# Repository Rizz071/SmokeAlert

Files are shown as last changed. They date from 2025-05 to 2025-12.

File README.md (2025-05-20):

# 🚨 SmokeAlert

**SmokeAlert** — это интеллектуальная беспроводная система пожарной сигнализации, разработанная для обеспечения безопасности в **жилых** и **промышленных** помещениях. Система сочетает в себе **долговечность**, **простоту установки** и **современные технологии связи**.

---

## 🔥 Основные особенности

- 📡 **LoRa 868MHz** — стабильная беспроводная связь с большим радиусом действия, не требующая государственной регистрации.
- 🛠️ **Установка за минуты** — настройка и добавление новых датчиков предельно упрощены.
- 📱 **Интеграция со смартфоном** — мгновенные уведомления и тревоги в приложении (через протокол MQTT, на собственной инфраструктуре).
- 🔋 **Долгий срок службы** — работа каждого датчика от 2 батареек AA до **1 года** без замены.
- ➕ **Гибкая масштабируемость** — к одной базовой станции можно подключить любое нужное количество датчиков.
- 🌐 **Два варианта выхода в интернет**:
  - через **Wi-Fi**
  - через **GSM-модуль**, где нет локальной сети

---

## ⚙️ Применение

- Частные дома и квартиры
- Офисы и административные здания
- Склады, мастерские, производственные помещения
- Объекты без постоянного подключения к WiFi

---

## 🤝 Контакты и вклад

Pull request'ы и предложения приветствуются!  
По вопросам сотрудничества — обращайтесь в [Issues](https://github.com/Rizz071/smokealert/issues) или откройте дискуссию.

---

**SmokeAlert** — безопасность должна быть доступной.

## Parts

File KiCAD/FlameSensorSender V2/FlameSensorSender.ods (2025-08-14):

Reference | Value | Footprint | Datasheet |  | Qty |  | AliExpress | ChipDip | Промэлектроника
BT1 | AA 2pcs | Battery:BatteryHolder_Keystone_2462_2xAA | ~ | Single-cell battery | 1 |  | 76 | 260 | нет
BZ1 | Buzzer SFM-20B | Buzzer_Beeper:Buzzer_12x9.5RM7.6 | ~ | Buzzer, polarized | 1 | https://aliexpress.ru/item/1005006076359267.html?sku_id=12000035619115303 | 56 | нет | нет
C1,C2,C3,C5,C6,C7 | 104,0603 | Capacitor_SMD:C_0603_1608Metric_Pad1.08x0.95mm_HandSolder | ~ | Unpolarized capacitor | 6 | 0.1 мкФ X7R 100В 10% 0603, GRM188R72A104KA35D | 1.4 | 3 | 3
C4 | 105,0603 | Capacitor_SMD:C_0603_1608Metric_Pad1.08x0.95mm_HandSolder | https://search.murata.co.jp/Ceramy/image/img/A01X/G101/ENG/GRM188R60J226MEA0-01.pdf | Unpolarized capacitor | 1 | 1 мкФ X7R 25В 10% 0603, GCM188R71E105KA64D, Конденсатор керамический smd (https://www.chipdip.ru/product/gcm188r71e105ka64d-murata) | 1,4 | 5 | 3
C8 | 16V220u,alum 6.3x7.7 | Capacitor_SMD:CP_Elec_6.3x7.7 | ~ | Polarized capacitor | 1 | ECAP SMD, 220мкФ, 16В, 105°C, 20%, 6.3x7.7мм, JCK1C221M063077, Конденсатор электролитический алюминиевый SMD (https://www.chipdip.ru/product0/9000565741) | 15 | 10 | нет
C9,C10,C13,C12 | 22u,0603 | Capacitor_SMD:C_0603_1608Metric_Pad1.08x0.95mm_HandSolder | https://search.murata.co.jp/Ceramy/image/img/A01X/G101/ENG/GRM188R60J226MEA0-01.pdf | Unpolarized capacitor | 4 | 22мкФ X5R 10В 20% 0603, GRM188R61A226ME15D, Конденсатор керамический smd (https://www.chipdip.ru/product0/9000318419) |  | 5 | 4
C11 | C_Polarized 100uF electrolitic | Capacitor_SMD:CP_Elec_5x5.4 | ~ | Polarized capacitor | 1 | https://aliexpress.ru/item/4000772249207.html?sku_id=10000007734222927 | 8 | 8
D1 | LED | LED_SMD:LED_1206_3216Metric_Pad1.42x1.75mm_HandSolder | ~ | Light emitting diode | 1 | https://aliexpress.ru/item/4000936830233.html?sku_id=10000011314281971 | 1 | 0 | 0
FB1 | FerriteBead | Inductor_SMD:L_0603_1608Metric_Pad1.05x0.95mm_HandSolder | ~ | Ferrite bead | 1 | MPZ1608D101BTA00, Ferrite Beads 100ohms 1A 60mOhms 0603 Ferrite Chip (https://www.chipdip.ru/product0/8006387224) | 3 | 24
J1,J2 | SWD | Connector_PinHeader_2.54mm:PinHeader_2x02_P2.54mm_Vertical | ~ | Generic connector, double row, 02x02, counter clockwise pin numbering scheme (similar to DIP package numbering), script generated (kicad-library-utils/schlib/autogen/connector/) | 2 | https://aliexpress.ru/item/1005006125301583.html?sku_id=12000035866886147 | 10
 | Sharp GP2Y1014AUOF |  |  |  | 1 | S6B-PH-K-S[LF][SN] (https://www.chipdip.ru/product0/8007977843) |  | 7
J3 | Sharp GP2Y1014AUOF | Connector_JST:JST_PH_S6B-PH-K_1x06_P2.00mm_Horizontal | ~ | Generic connector, single row, 01x06, script generated | 1 | PHR-6, Корпус разъема розетка на кабель 2.0 мм 6pin (https://www.chipdip.ru/product/phr-6) | 430 | 18
J4 | JST-PH PHR-2 |  | ~ | Generic connector, single row, 01x02, script generated | 1 | PHR-2, Корпус разъема розетка на кабель 2.0 мм 2pin (https://www.chipdip.ru/product/phr-2-2) |  | 18
J5 | JST-PH B2B-PH-K-S | Connector_JST:JST_PH_S2B-PH-K_1x02_P2.00mm_Horizontal | ~ | Generic connector, single row, 01x02, script generated | 1 | S2B-PH-K-S [LF][SN] (https://www.chipdip.ru/product0/8002744024) |  | 4
J6 | Conn_01x04_Socket | Connector_JST:JST_PH_S4B-PH-K_1x04_P2.00mm_Horizontal | ~ | Generic connector, single row, 01x04, script generated | 1 | S4B-PH-K-S [LF][SN] (https://www.chipdip.ru/product0/8002744025) |  | 7
J7 | Conn_01x04_Pin |  | ~ | Generic connector, single row, 01x04, script generated | 1 | PHR-4, Корпус разъема розетка на кабель 2.0 мм 4pin (https://www.chipdip.ru/product/phr-4) |  | 18
J8 | 6 Pin USB-C Type USB Connector with case |  |  | USB Power-Only 6P Type-C Receptacle connector | 1 | https://aliexpress.ru/item/1005005750734799.html?pdp_trigger_item_id=0_1005006256311650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 | 117
L1,L2 | 0.47u | Footprints:INDC2016X120N | https://search.murata.co.jp/Ceramy/image/img/P02/J(E)TE243A-0006.pdf | Inductor DFE201612E-R47M=P2 | 2 | DFE201612E-R47M=P2 (https://www.chipdip.ru/product0/8008306444) |  | 9
Q1,Q3,Q6 | AO3401A | Package_TO_SOT_SMD:SOT-23-3 | http://www.aosmd.com/pdfs/datasheet/AO3401A.pdf | -4.0A Id, -30V Vds, P-Channel MOSFET, SOT-23 | 3 | AO3401A, Транзистор P-MOSFET 30В 4.2А [SOT-23-3] (https://www.chipdip.ru/product/ao3401a-umw) |  | 4
Q2,Q4,Q5 | AO3400A | Package_TO_SOT_SMD:SOT-23-3 | http://www.aosmd.com/pdfs/datasheet/AO3400A.pdf | 30V Vds, 5.7A Id, N-Channel MOSFET, SOT-23 | 3 | AO3400A, Транзистор N-MOSFET 30В 5.8А 1.4Вт [SOT-23-3.] (https://www.chipdip.ru/product/ao3400a) |  | 10
R1,R2,R7,R11,R12,R16,R17,R19 | 10k,0603 | Resistor_SMD:R_0603_1608Metric_Pad0.98x0.95mm_HandSolder | https://www.vishay.com/docs/20035/dcrcwe3.pdf,~ | Resistor | 8 | 0.1Вт 0603 10 кОм, 1%, AC0603FR-0710KL, Чип резистор (SMD) (https://www.chipdip.ru/product0/9000695897) |  | 6
R3,R8,R18 | 10,0603 | Resistor_SMD:R_0603_1608Metric_Pad0.98x0.95mm_HandSolder | ~ | Resistor | 3 | 0.1Вт 0603 10 Ом, 1%, RC0603FR-0710RL, Чип резистор (SMD) (https://www.chipdip.ru/product/rc0603fr-0710rl-rezistor) |  | 2
R4,R5 | 220,0603 | Resistor_SMD:R_0603_1608Metric_Pad0.98x0.95mm_HandSolder | ~ | Resistor | 2 | 0.1Вт 0603 220 Ом, 1%, RC0603FR-07220RL, Чип резистор (SMD) (https://www.chipdip.ru/product0/9000179829) |  | 2
R6,R10 | 330,0603 | Resistor_SMD:R_0603_1608Metric_Pad0.98x0.95mm_HandSolder | ~ | Resistor | 2 | 0.1Вт 0603 330 Ом, 1%, RC0603FR-07330RL, Чип резистор (SMD) (https://www.chipdip.ru/product0/9000396128) |  | 2
R9 | 150,0603 | Resistor_SMD:R_0603_1608Metric_Pad0.98x0.95mm_HandSolder | ~ | Resistor | 1 | 0603SAF1500T5E, Резистор: thick film, SMD, 0603, 150Ом, 0,1Вт, ±1%, -55-155°C (https://www.chipdip.ru/product0/8007875741) |  | 2
R13,R22 | 100k,0603 | Resistor_SMD:R_0603_1608Metric_Pad0.98x0.95mm_HandSolder | https://www.vishay.com/docs/20035/dcrcwe3.pdf | Resistor | 2 | 0.1Вт 0603 100 кОм, 1%, RC0603FR-07100KL, Чип резистор (SMD) (https://www.chipdip.ru/product0/9000632023) |  | 2
R14 | 511k,0603 | Resistor_SMD:R_0603_1608Metric_Pad0.98x0.95mm_HandSolder | https://www.vishay.com/docs/20035/dcrcwe3.pdf | Resistor | 1 | 0.1Вт 0603 510 кОм, 1%, RC0603FR-07510KL, Чип резистор (SMD) (https://www.chipdip.ru/product/rc0603fr-07510kl-yageo) |  | 2
R15,R24 | 91k,0603 | Resistor_SMD:R_0603_1608Metric_Pad0.98x0.95mm_HandSolder | https://www.vishay.com/docs/20035/dcrcwe3.pdf | Resistor | 2 | 0.1Вт 0603 91 кОм, 1%, RC0603FR-0791KL, Чип резистор (SMD) (https://www.chipdip.ru/product0/9000618649) |  | 2
R20,R21 | 5.1k,0603 | Resistor_SMD:R_0603_1608Metric_Pad0.98x0.95mm_HandSolder | ~ | Resistor | 2 | 0.1Вт 0603 5.1 кОм, 5%, RC0603JR-075K1L, Чип резистор (SMD) (https://www.chipdip.ru/product0/9000103442) |  | 2
R23 | 806k,0603 | Resistor_SMD:R_0603_1608Metric_Pad0.98x0.95mm_HandSolder | https://www.vishay.com/docs/20035/dcrcwe3.pdf | Resistor | 1 | WR06X8063FTL, Thick Film Resistors - SMD 0603 806K 1% Lead Free (https://www.chipdip.ru/product0/8008405525) |  | 30
SW1 | SW_Push | Button_Switch_THT:SW_PUSH_6mm_H4.3mm | ~ | Push button switch, generic, two pins | 1 | 1-1825910-0 (FSM6JH), Кнопка тактовая h=7 мм SPST (https://www.chipdip.ru/product/tyco-1-1825910-0-fsm6jh) |  | 13
SW2 | SW_Push | Button_Switch_SMD:SW_Push_1TS009xxxx-xxxx-xxxx_6x6x5mm | ~ | Push button switch, generic, two pins | 1 | https://aliexpress.ru/item/4000678658427.html?pdp_trigger_item_id=0_1005009311663697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 |  | 5
U1 | STM32F103C6Tx | Package_QFP:LQFP-48_7x7mm_P0.5mm | https://www.st.com/resource/en/datasheet/stm32f103c6.pdf | STMicroelectronics Arm Cortex-M3 MCU, 32KB flash, 10KB RAM, 72 MHz, 2.0-3.6V, 37 GPIO, LQFP48 | 1 | STM32F103C8T6, Микроконтроллер 32-Бит, Cortex-M3, 72МГц, 64КБ Flash, USB, CAN [LQFP-48.] (https://www.chipdip.ru/product/stm32f103c8t6) |  | 140
U2 | Ra-01SCH-P | RF_Module:Ai-Thinker-Ra-01-LoRa | http://wiki.ai-thinker.com/_media/lora/docs/c048ps01a1_ra-02_product_specification_v1.1.pdf | Ai-Thinker Ra-02 410-525 MHz LoRa Module, SPI interface, U.FL antenna connector | 1 | https://aliexpress.ru/item/4001148156263.html?sku_id=12000043451828807 | 299
U3 | TVS0500DRV | Package_SON:WSON-6-1EP_2x2mm_P0.65mm_EP1x1.6mm | http://www.ti.com/lit/ds/symlink/tvs0500.pdf | Flat-Clamp Surge Protection Device. 5Vrwm, WSON-6 | 1 | TVS0500DRVR (https://www.chipdip.ru/product0/8003874408) |  | 110
U4,U6 | TPS63802DLAR | Footprints:VREG_TPS63802DLAR | https://www.ti.com/lit/ds/symlink/tps63802.pdf?ts=1746895174737 |  | 2 | TPS63802DLAR, Buck-boost преобразователь напряжения ADJ VSON-HR-10(3x2) (https://www.chipdip.ru/product/tps63802dlat) |  | 130
U5 | TPS2116DRL | Package_TO_SOT_SMD:SOT-583-8 | https://www.ti.com/lit/ds/symlink/tps2116.pdf | 2 Channnels Power Mux with Manual and Priority Switchover, 1.6-5.5V Input Voltage, 2.5A Output Current, Ron 40 mOhm, SOT-583-8 | 1 | TPS2116DRLR, Выключатель распределения питания SOT-583 (https://www.chipdip.ru/product0/8048099577) |  | 87
 |  |  |  |  | 12 | SPH-002T-P0.5L (https://www.chipdip.ru/product/sph-002t-p0.5l) | 3

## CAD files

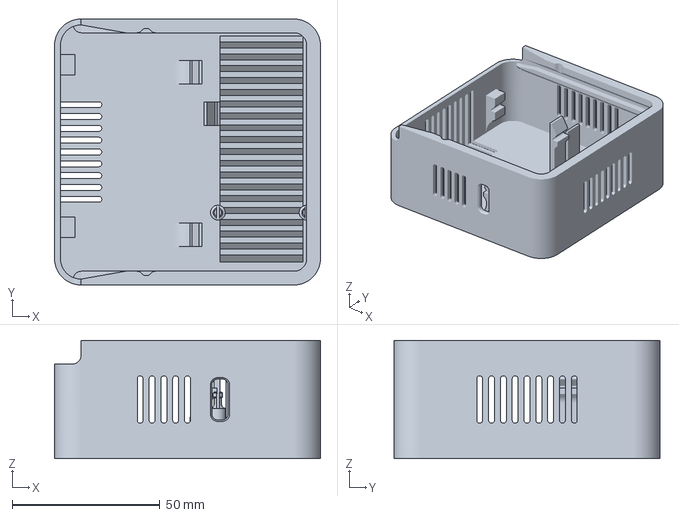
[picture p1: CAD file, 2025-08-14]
Creo/SensorSender/prt0001.3mf
90.0 x 90.0 x 40.0 mm

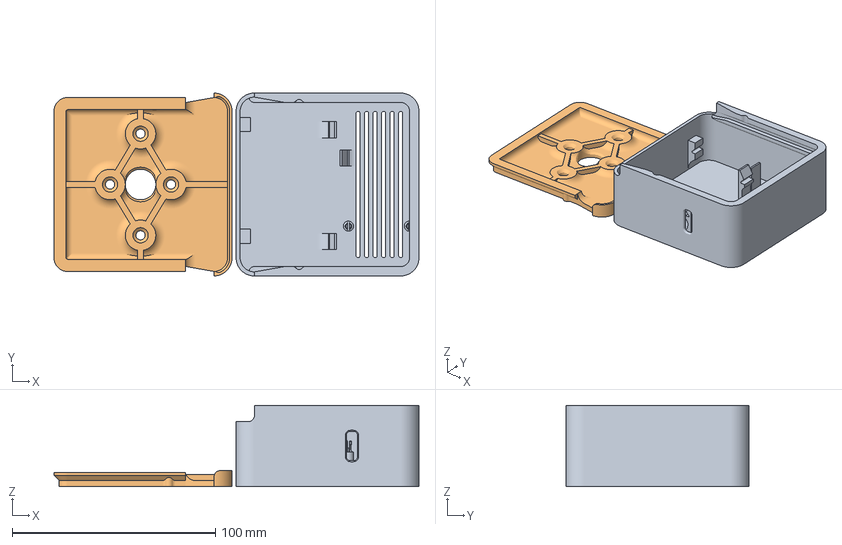
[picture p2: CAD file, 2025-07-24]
Creo/SensorSender_Sharp_sensor/prt0001.3mf
179.6 x 90.0 x 40.0 mm
prt0001.stp
prt0005.stp

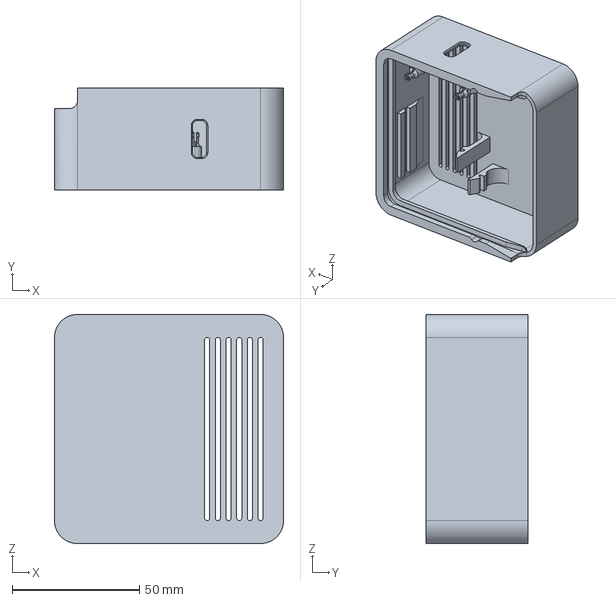
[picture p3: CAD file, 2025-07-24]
Creo/SensorSender_Sharp_sensor/Slider/prt0001.stp
90.0 x 40.0 x 90.0 mm

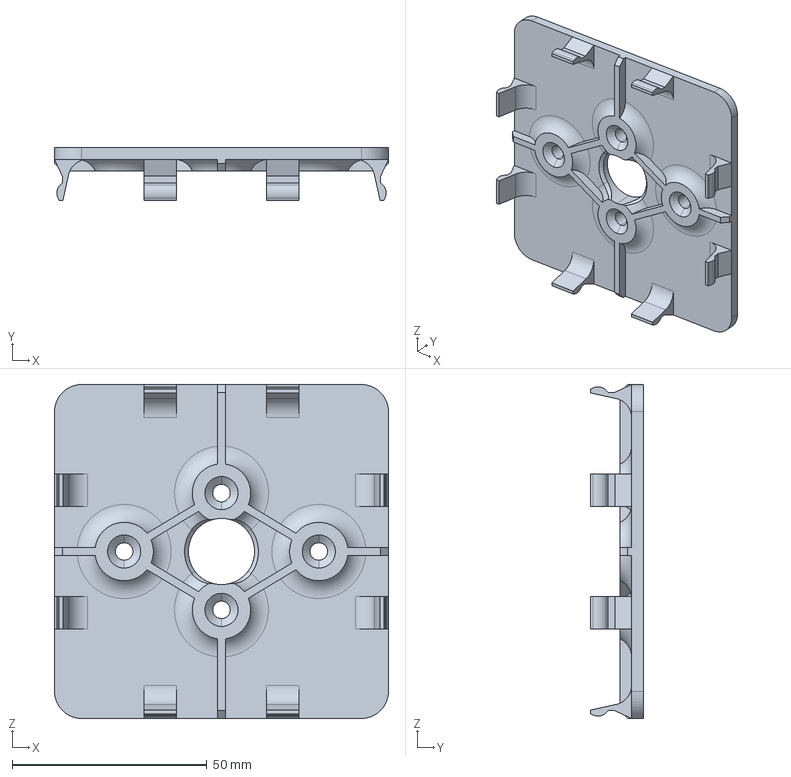
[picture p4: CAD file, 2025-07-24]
Creo/SensorSender_Sharp_sensor/Snaps/prt0005.stp
85.8 x 13.5 x 85.8 mm

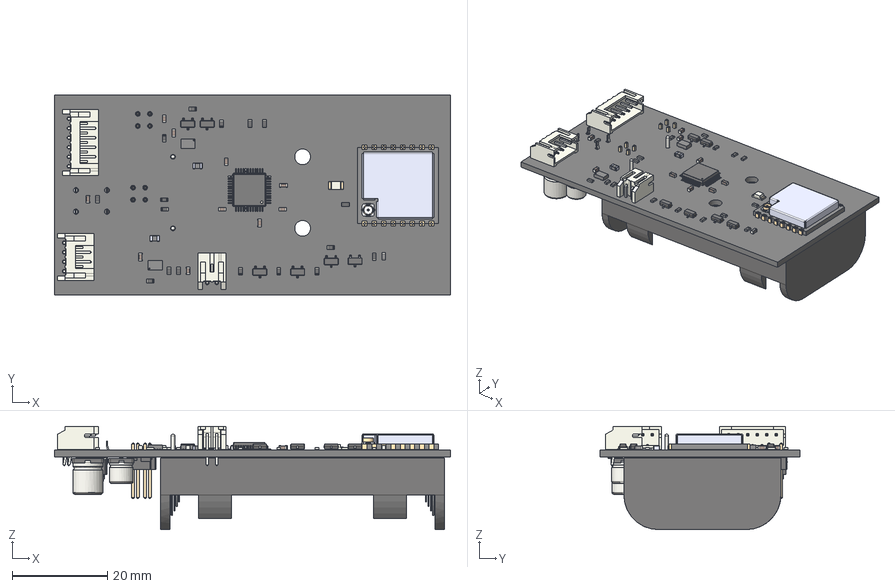
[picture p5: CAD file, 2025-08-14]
KiCAD/FlameSensorSender V2/FlameSensorSender.step
83.0 x 42.0 x 21.6 mm
R_0603_1608Metric x 24
C_0603_1608Metric x 11
TPS63802DLAR x 2
SOT-23-3 x 6
JST_PH_S4B-PH-K_1x04_P2.00mm_Horizontal
INDC2016X120N x 2
LED_1206_3216Metric
L_0603_1608Metric
RA-02
JST_PH_S6B-PH-K_1x06_P2.00mm_Horizontal
JST_PH_S2B-PH-K_1x02_P2.00mm_Horizontal
LQFP-48_7x7mm_P0.5mm
pin_1
pin_2
PinHeader_2x02_P2.54mm_Vertical x 2
BatteryHolder_Keystone_2462_2xAA
SOT-583-8
SW_PUSH_6mm_H4.3mm
CP_Elec_6.3x7.7
CP_Elec_5x5.4
WSON-6-1EP_2x2mm_P0.65mm_EP1x1.6mm
FlameSensorSender_PCB

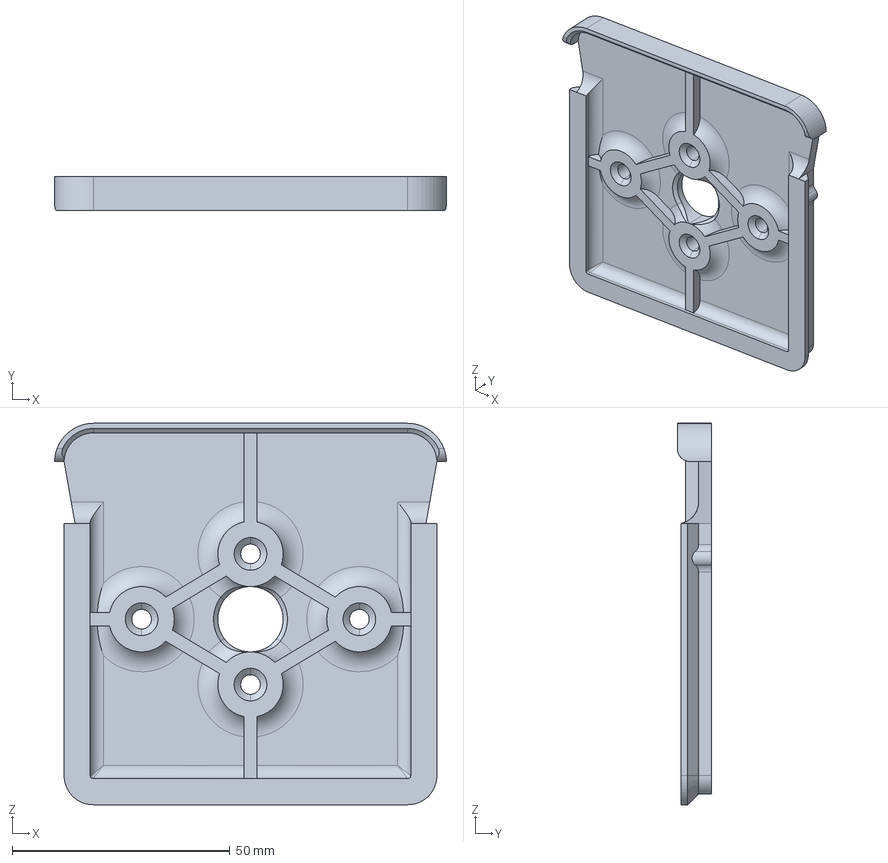
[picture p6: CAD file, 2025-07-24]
Creo/SensorSender_Sharp_sensor/Slider/prt0005.stp
90.0 x 7.90 x 87.6 mm

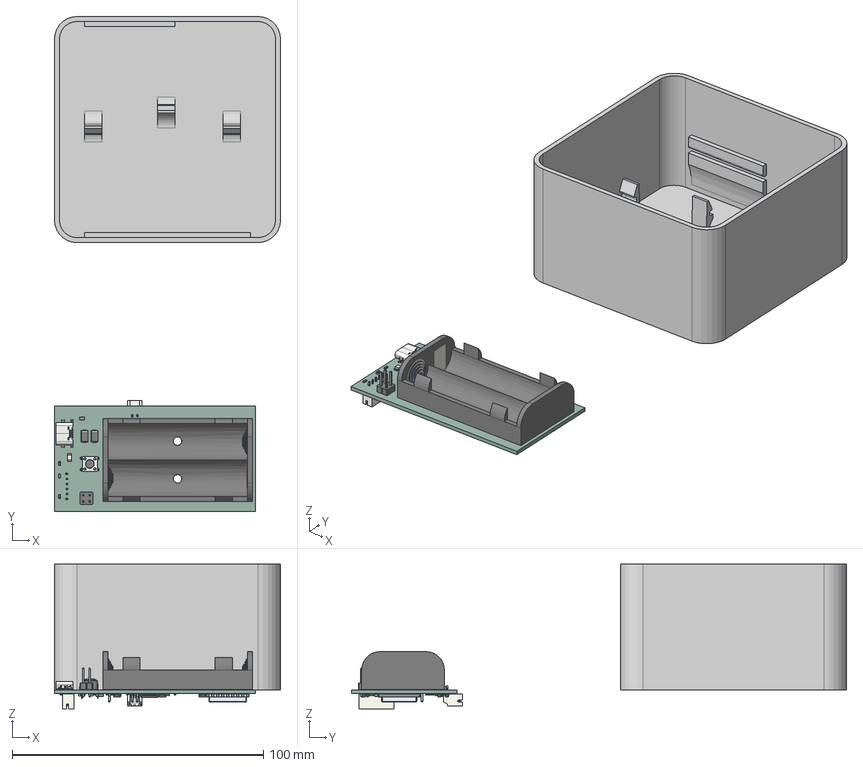
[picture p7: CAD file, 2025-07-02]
KiCAD/FlameSensorSender V2/FlameSenderCover.step
90.0 x 197.0 x 57.6 mm
R_0603_1608Metric x 20
SOT-23 x 2
C_0603_1608Metric x 12
TPS63802DLAR x 2
SOT-23-3
RA-02
JST_PH_B6B-PH-K_1x06_P2.00mm_Vertical
JST_PH_S2B-PH-K_1x02_P2.00mm_Horizontal
LQFP-48_7x7mm_P0.5mm
PinHeader_2x02_P2.54mm_Vertical
D_SMA x 2
LED_1206_3216Metric
BatteryHolder_Keystone_2462_2xAA
C_0805_2012Metric
SW_PUSH_6mm_H4.3mm
USB_C_Receptacle_GCT_USB4135-GF-A_6P_TopMnt_Horizontal
FlameSensorSender_PCB

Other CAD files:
Creo/SensorSender/Slider/prt0001.stp
Creo/SensorSender_Sharp_sensor/Snaps/prt0001.stp
Creo/SensorSender_Sharp_sensor/Slider/prt0001.3mf
Creo/SensorSender_Sharp_sensor/Slider/prt0001.stl
Creo/SensorSender_Sharp_sensor/Snaps/prt0001.3mf
Creo/SensorSender_Sharp_sensor/Snaps/prt0001.stl
KiCAD/FlameSensorSender V2/FlameSensorSender.f3d

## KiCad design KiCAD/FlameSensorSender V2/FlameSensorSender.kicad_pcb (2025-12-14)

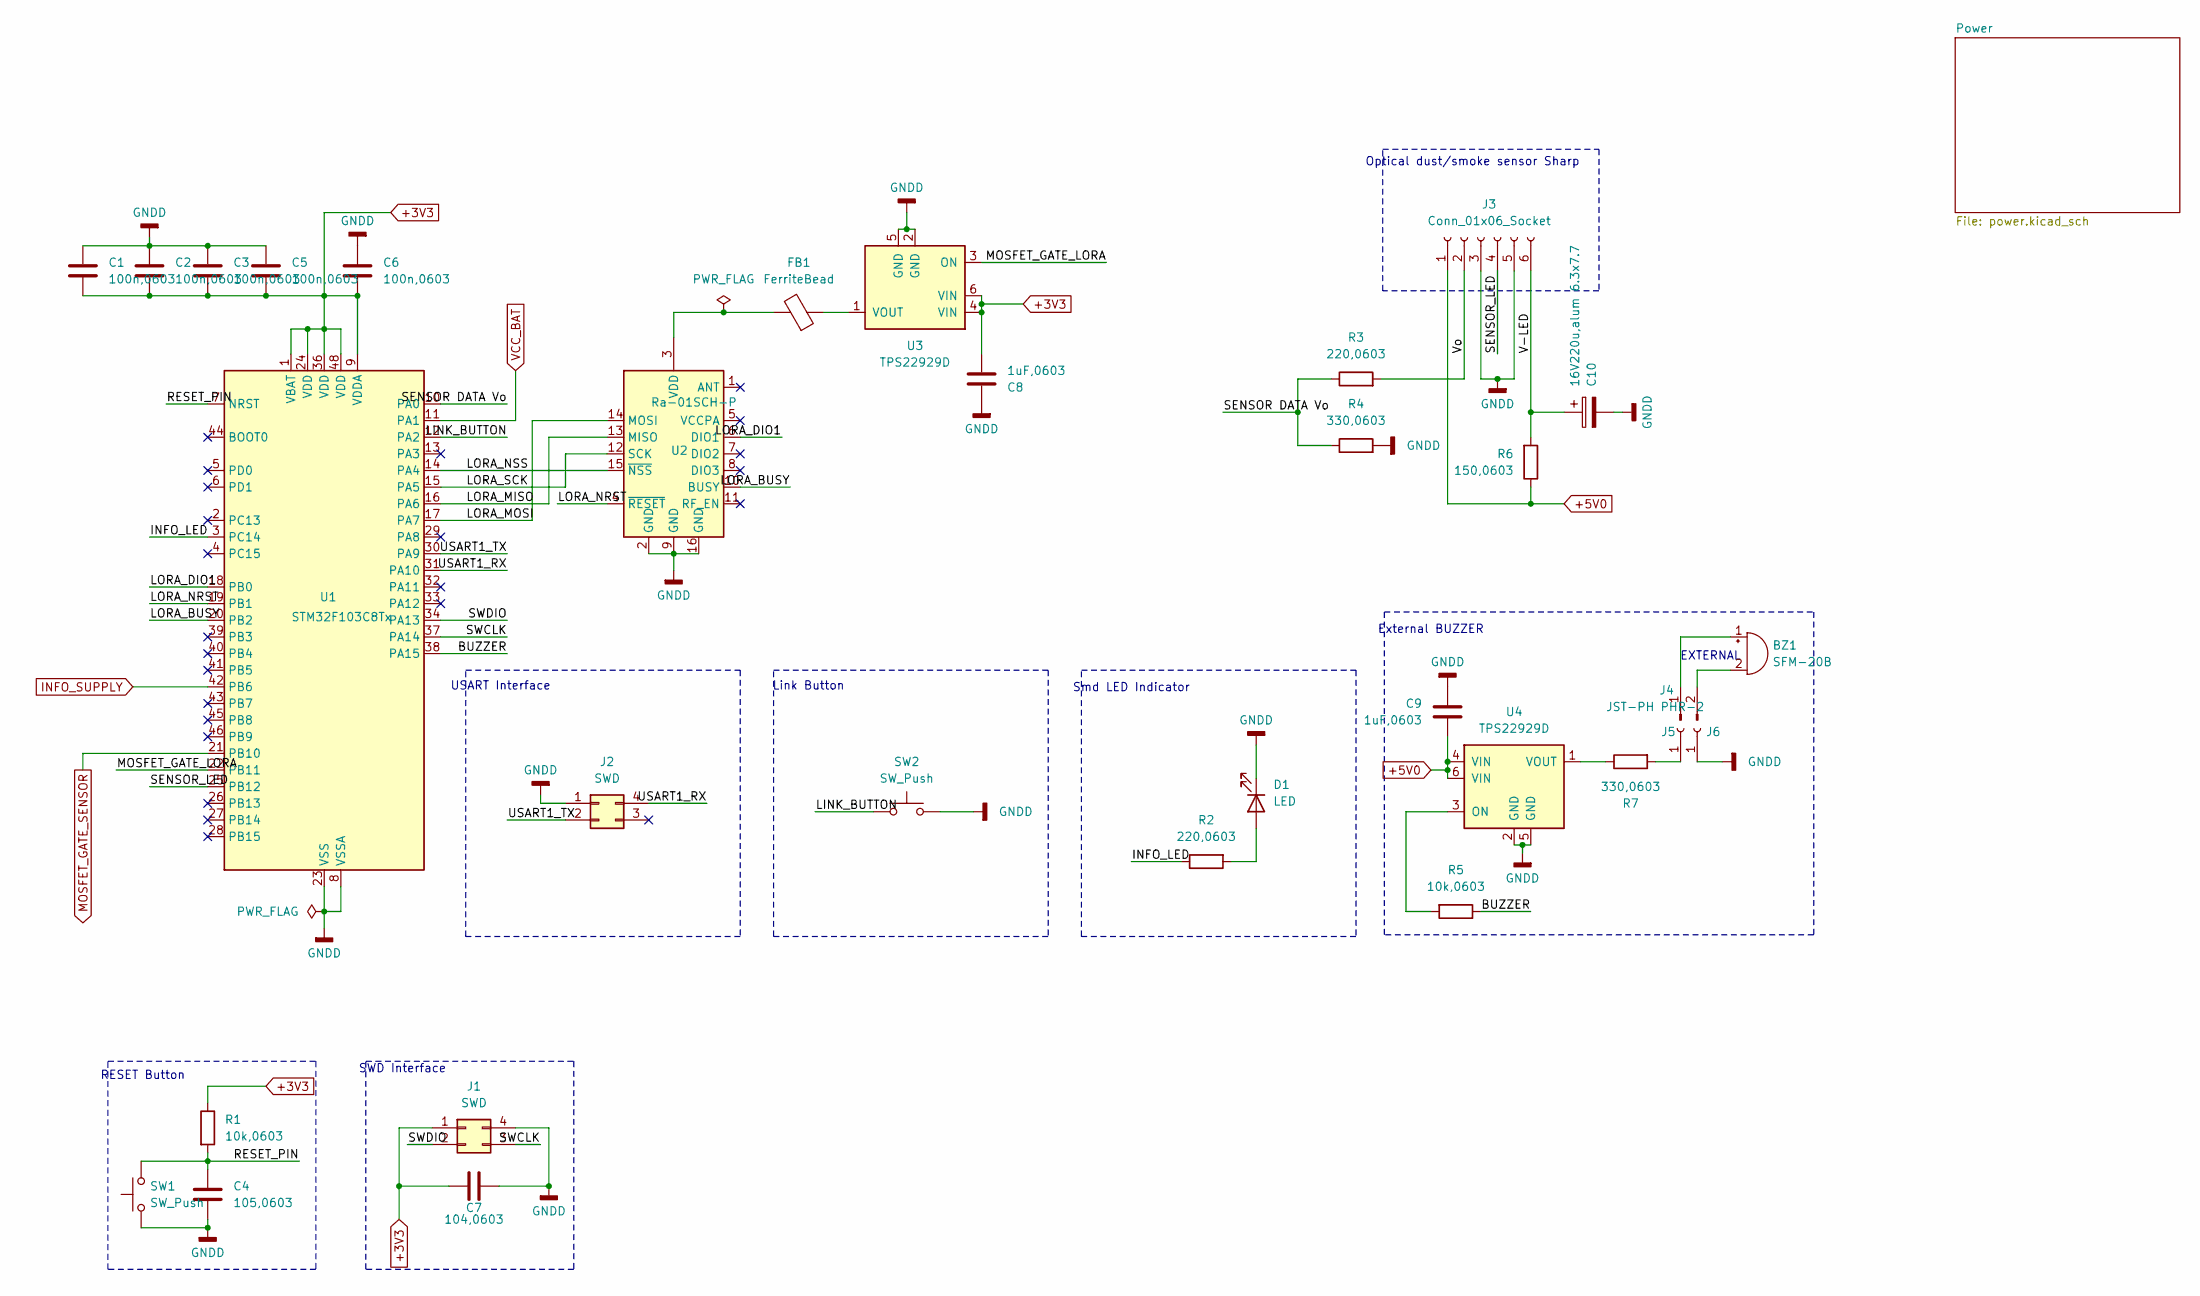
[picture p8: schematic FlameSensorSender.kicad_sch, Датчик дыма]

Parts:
BZ1: SFM-20B; Buzzer_12x9.5RM7.6
C1, C2, C3, C5, C6: 100n,0603; C_0603_1608Metric_Pad1.08x0.95mm_HandSolder
C4: 105,0603; C_0603_1608Metric_Pad1.08x0.95mm_HandSolder
C7: 104,0603; C_0603_1608Metric_Pad1.08x0.95mm_HandSolder
C8, C9: 1uF,0603; C_0603_1608Metric_Pad1.08x0.95mm_HandSolder
C10: 16V220u,alum 6.3x7.7; CP_Elec_6.3x7.7
D1: LED; LED_1206_3216Metric_Pad1.42x1.75mm_HandSolder
FB1: FerriteBead; L_0603_1608Metric_Pad1.05x0.95mm_HandSolder
J1, J2: SWD; PinHeader_2x02_P2.54mm_Vertical
J3: Conn_01x06_Socket; CONN_B6B-ZR-SM4-TF_JST
J4: JST-PH PHR-2
J5, J6: Conn_01x01_Socket; SolderWirePad_1x01_SMD_2x4mm
R1, R5: 10k,0603; R_0603_1608Metric_Pad0.98x0.95mm_HandSolder
R2, R3: 220,0603; R_0603_1608Metric_Pad0.98x0.95mm_HandSolder
R4, R7: 330,0603; R_0603_1608Metric_Pad0.98x0.95mm_HandSolder
R6: 150,0603; R_0603_1608Metric_Pad0.98x0.95mm_HandSolder
SW1: SW_Push; SW_PUSH_6mm_H4.3mm
SW2: SW_Push; SW_Push_1TS009xxxx-xxxx-xxxx_6x6x5mm
U1: STM32F103C8Tx; LQFP-48_7x7mm_P0.5mm
U2: Ra-01SCH-P; Ai-Thinker-Ra-01-LoRa
U3, U4: TPS22929D; SOT-23-6

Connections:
+3V3: C1.1, C2.1, C3.1, C5.1, C6.1, C7.2, C8.1, J1.1, R1.1, U1.1 (VBAT), U1.9 (VDDA), U1.24 (VDD), U1.36 (VDD), U1.48 (VDD), U3.4 (VIN), U3.6 (VIN); also elsewhere on the board
+5V0: C9.1, J3.1, R6.1, U4.4 (VIN), U4.6 (VIN); also elsewhere on the board
/BUZZER: R5.1, U1.38 (PA15)
/INFO_LED: R2.1, U1.3 (PC14)
/LINK_BUTTON: SW2.1, U1.12 (PA2)
/LORA_BUSY: U1.20 (PB2), U2.10 (BUSY)
/LORA_DIO1: U1.18 (PB0), U2.6 (DIO1)
/LORA_MISO: U1.16 (PA6), U2.13 (MISO)
/LORA_MOSI: U1.17 (PA7), U2.14 (MOSI)
/LORA_NRST: U1.19 (PB1), U2.4 (~RESET)
/LORA_NSS: U1.14 (PA4), U2.15 (~NSS)
/LORA_SCK: U1.15 (PA5), U2.12 (SCK)
/MOSFET_GATE_LORA: U1.22 (PB11), U3.3 (ON)
/RESET_PIN: C4.1, R1.2, SW1.2, U1.7 (NRST)
/SENSOR DATA Vo: R3.1, R4.1, U1.10 (PA0)
/SENSOR_LED: J3.4, U1.25 (PB12)
/SWCLK: J1.3, U1.37 (PA14)
/SWDIO: J1.2, U1.34 (PA13)
/USART1_RX: J2.4, U1.31 (PA10)
/USART1_TX: J2.2, U1.30 (PA9)
/V-LED: C10.1, J3.6, R6.2
/Vo: J3.2, R3.2
GNDD: C1.2, C2.2, C3.2, C4.2, C5.2, C6.2, C7.1, C8.2, C9.2, C10.2, D1.1 (K), J1.4, J2.1, J3.3, J3.5, J6.1, R4.2, SW1.1, SW2.2, U1.8 (VSSA), U1.23 (VSS), U1.35 (VSS), U1.47 (VSS), U2.2 (GND), U2.9 (GND), U2.16 (GND), U3.2 (GND), U3.5 (GND), U4.2 (GND), U4.5 (GND); also elsewhere on the board
INFO_SUPPLY: U1.42 (PB6); also elsewhere on the board
MOSFET_GATE_SENSOR: U1.21 (PB10); also elsewhere on the board
unnamed: BZ1.1 (+), J4.1
unnamed: BZ1.2 (-), J4.2
unnamed: D1.2 (A), R2.2
unnamed: J5.1, R7.2
unnamed: FB1.2, U2.3 (VDD)
unnamed: FB1.1, U3.1 (VOUT)
unnamed: R5.2, U4.3 (ON)
unnamed: R7.1, U4.1 (VOUT)
VCC_BAT: U1.11 (PA1); also elsewhere on the board

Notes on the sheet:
SWD Interface
RESET Button
Smd LED Indicator
Link Button
USART Interface
External BUZZER
Optical dust/smoke sensor Sharp
EXTERNAL

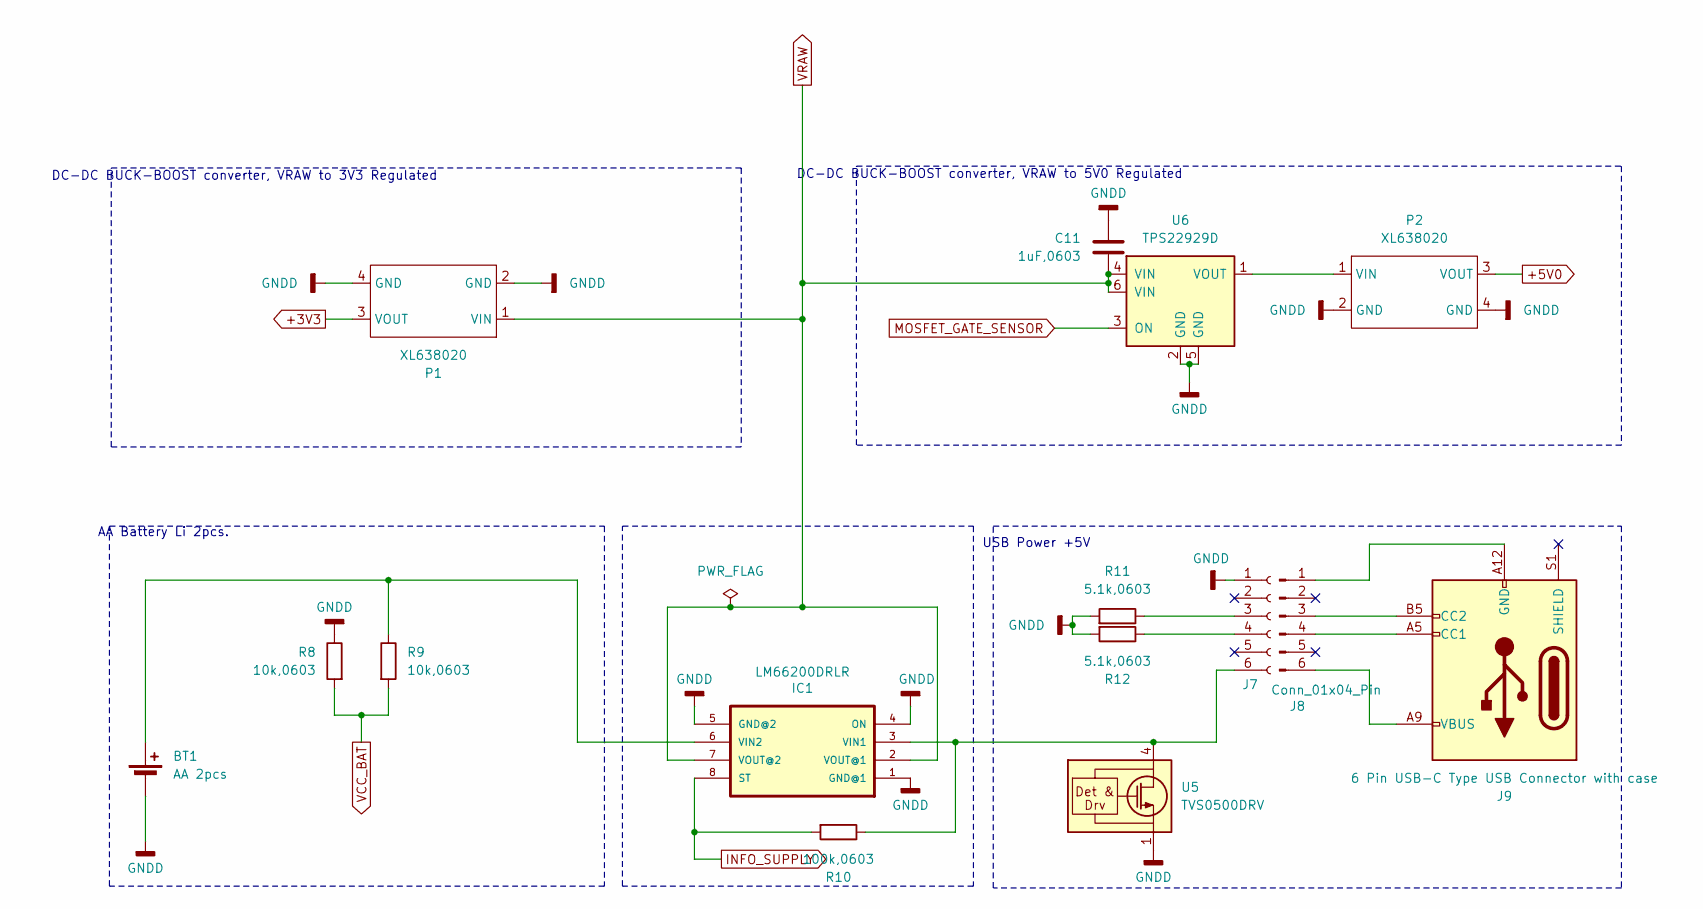
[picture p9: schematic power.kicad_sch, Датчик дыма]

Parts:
BT1: AA 2pcs; BatteryHolder_Keystone_2462_2xAA
C11: 1uF,0603; C_0603_1608Metric_Pad1.08x0.95mm_HandSolder
IC1: LM66200DRLR; SOT-5X3_DRL_TEX-M
J7: Conn_01x06_Socket; JST_PH_B6B-PH-K_1x06_P2.00mm_Vertical
J8: Conn_01x04_Pin
J9: 6 Pin USB-C Type USB Connector with case
P1, P2: XL638020; XL63802
R8, R9: 10k,0603; R_0603_1608Metric_Pad0.98x0.95mm_HandSolder
R10: 100k,0603; R_0603_1608Metric_Pad0.98x0.95mm_HandSolder
R11, R12: 5.1k,0603; R_0603_1608Metric_Pad0.98x0.95mm_HandSolder
U5: TVS0500DRV; WSON-6-1EP_2x2mm_P0.65mm_EP1x1.6mm
U6: TPS22929D; SOT-23-6

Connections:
+3V3: P1.3 (VOUT); also elsewhere on the board
+5V0: P2.3 (VOUT); also elsewhere on the board
GNDD: BT1.2 (-), C11.2, IC1.1 (GND@1), IC1.4 (ON), IC1.5 (GND@2), J7.1, P1.2 (GND), P1.4 (GND), P2.2 (GND), P2.4 (GND), R8.1, R11.2, R12.2, U5.1 (GND), U5.2 (GND), U5.3 (GND), U5.7 (GND), U6.2 (GND), U6.5 (GND); also elsewhere on the board
INFO_SUPPLY: IC1.8 (ST), R10.2; also elsewhere on the board
MOSFET_GATE_SENSOR: U6.3 (ON); also elsewhere on the board
unnamed: BT1.1 (+), IC1.6 (VIN2), R9.1
unnamed: IC1.3 (VIN1), J7.6, R10.1, U5.4 (IN), U5.5 (IN), U5.6 (IN)
unnamed: J7.3, R11.1
unnamed: J7.4, R12.1
unnamed: J8.1, J9.A12 (GND), J9.B12 (GND)
unnamed: J8.3, J9.B5 (CC2)
unnamed: J8.4, J9.A5 (CC1)
unnamed: J8.6, J9.A9 (VBUS), J9.B9 (VBUS)
unnamed: P2.1 (VIN), U6.1 (VOUT)
VCC_BAT: R8.2, R9.2; also elsewhere on the board
VRAW: C11.1, IC1.2 (VOUT@1), IC1.7 (VOUT@2), P1.1 (VIN), U6.4 (VIN), U6.6 (VIN)

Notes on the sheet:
AA Battery Li 2pcs.
DC-DC BUCK-BOOST converter, VRAW to 3V3 Regulated
DC-DC BUCK-BOOST converter, VRAW to 5V0 Regulated
USB Power +5V

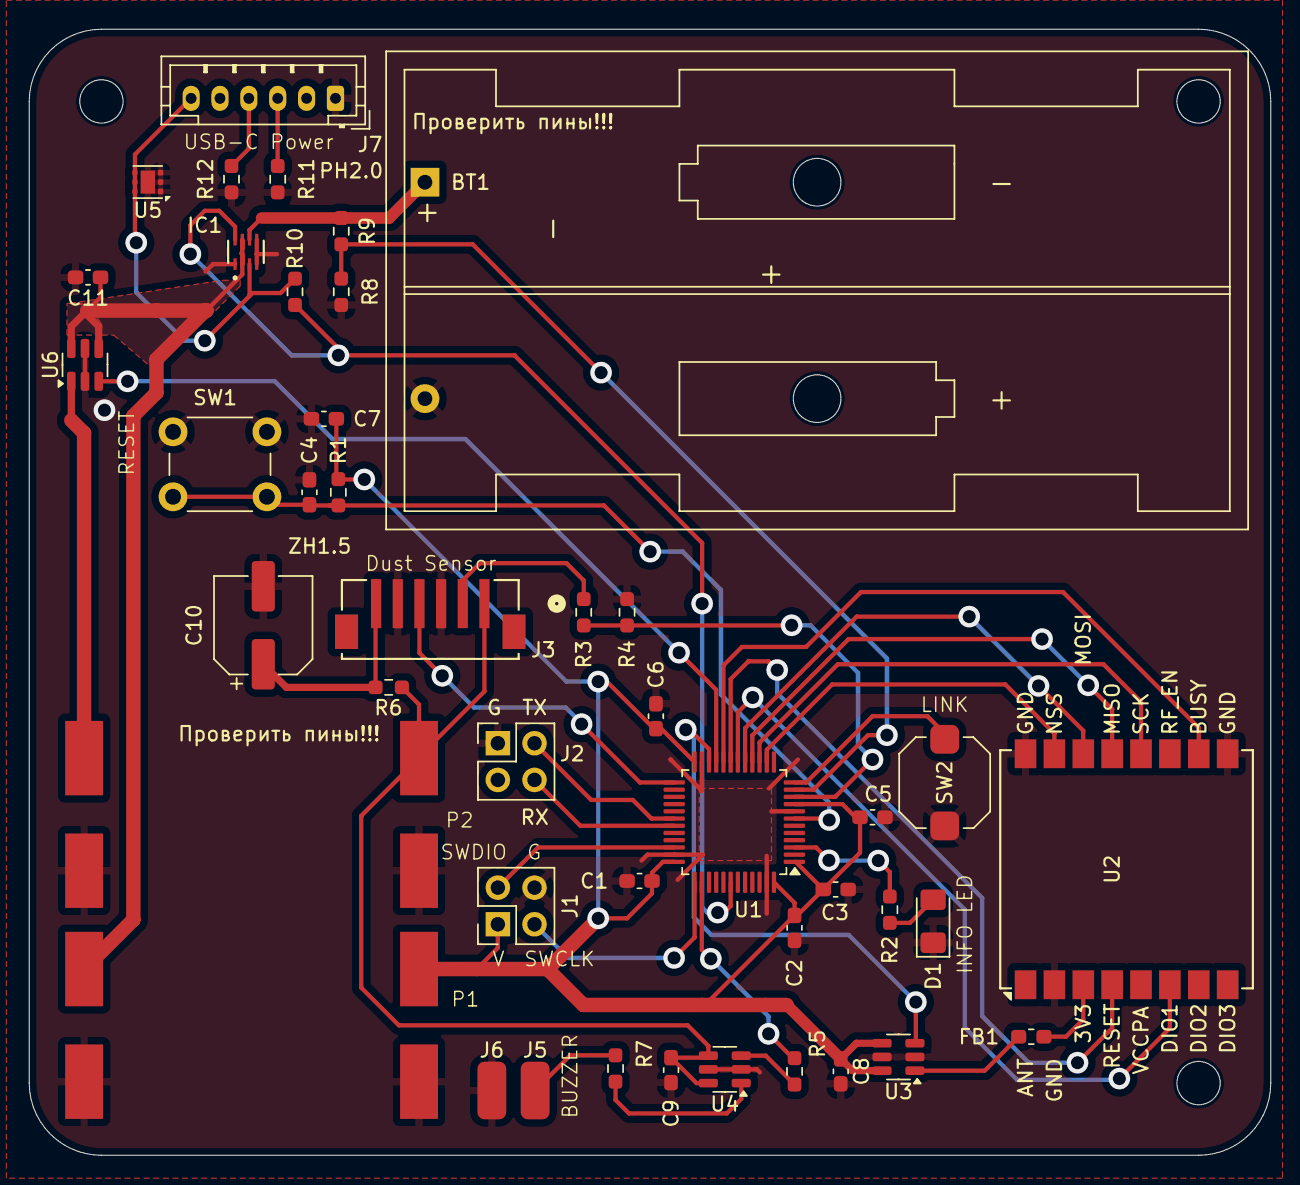
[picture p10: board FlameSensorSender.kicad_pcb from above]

Board: 2 copper layers, 86.0 x 78.0 mm, 43 parts (0 on the bottom side), 38 nets.

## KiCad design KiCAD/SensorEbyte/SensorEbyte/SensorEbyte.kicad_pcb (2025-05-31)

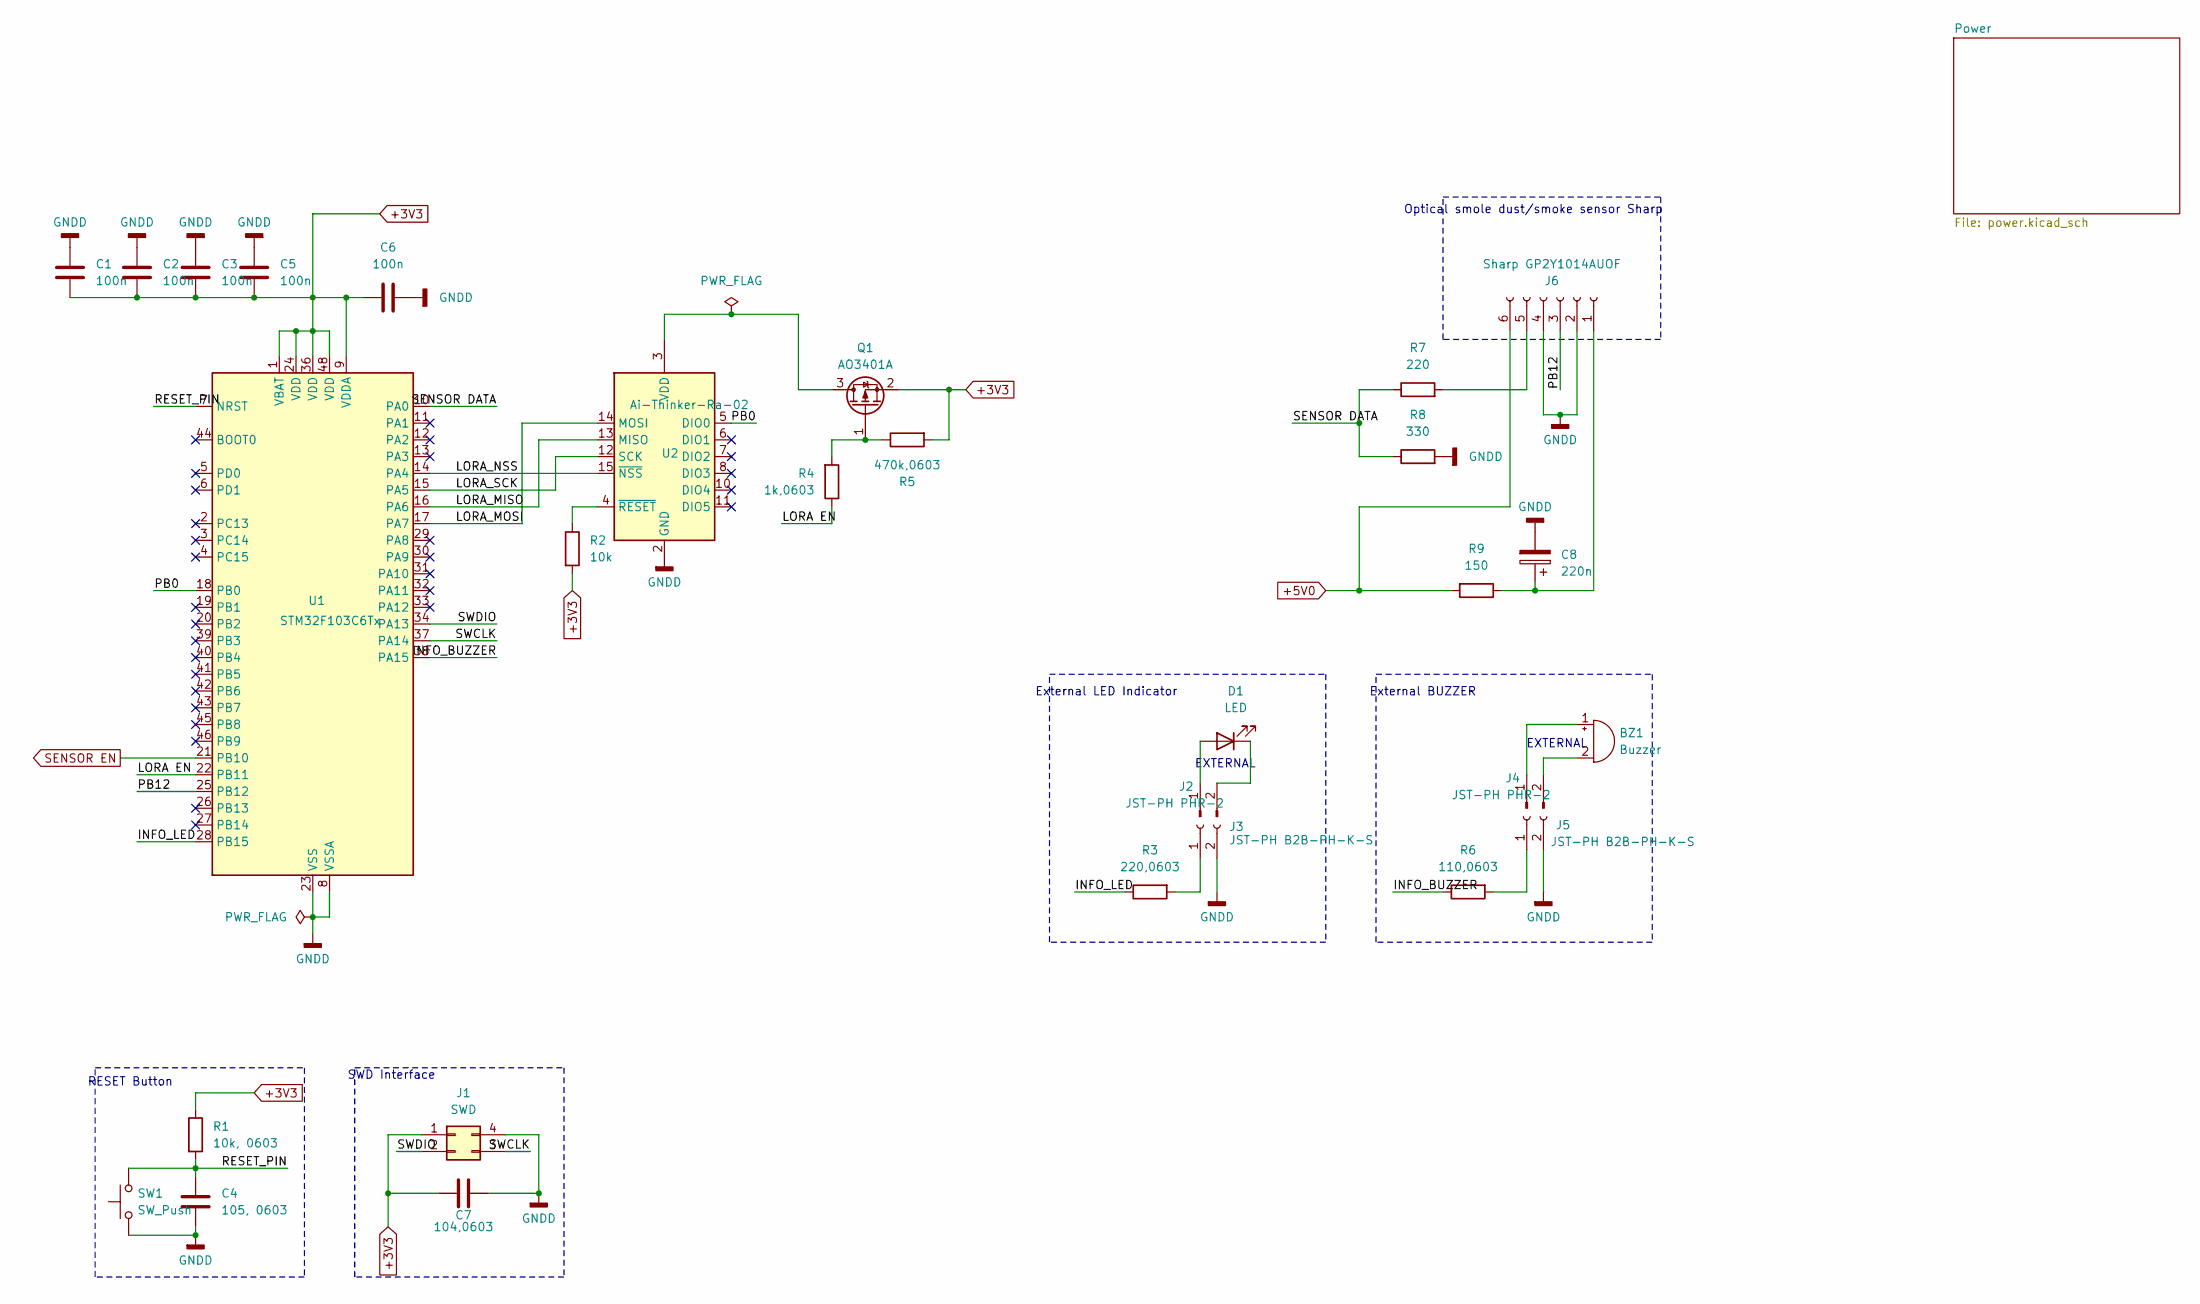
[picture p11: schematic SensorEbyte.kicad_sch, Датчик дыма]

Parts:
BZ1: Buzzer
C1, C2, C3, C5, C6: 100n; C_0603_1608Metric_Pad1.08x0.95mm_HandSolder
C4: 105, 0603; C_0603_1608Metric_Pad1.08x0.95mm_HandSolder
C7: 104,0603; C_0603_1608Metric_Pad1.08x0.95mm_HandSolder
C8: 220n; C_0603_1608Metric_Pad1.08x0.95mm_HandSolder
D1: LED; LED_D5.0mm
J1: SWD; PinHeader_2x02_P2.54mm_Vertical
J2, J4: JST-PH PHR-2
J3, J5: JST-PH B2B-PH-K-S; JST_PH_B2B-PH-K_1x02_P2.00mm_Vertical
J6: Sharp GP2Y1014AUOF; JST_PH_B6B-PH-K_1x06_P2.00mm_Vertical
Q1: AO3401A; SOT-23-3
R1: 10k, 0603; R_0603_1608Metric_Pad0.98x0.95mm_HandSolder
R2: 10k; R_0603_1608Metric_Pad0.98x0.95mm_HandSolder
R3: 220,0603; R_0603_1608Metric_Pad0.98x0.95mm_HandSolder
R4: 1k,0603; R_0603_1608Metric_Pad0.98x0.95mm_HandSolder
R5: 470k,0603; R_0603_1608Metric_Pad0.98x0.95mm_HandSolder
R6: 110,0603; R_0603_1608Metric_Pad0.98x0.95mm_HandSolder
R7: 220; R_0603_1608Metric_Pad0.98x0.95mm_HandSolder
R8: 330; R_0603_1608Metric_Pad0.98x0.95mm_HandSolder
R9: 150; R_0603_1608Metric_Pad0.98x0.95mm_HandSolder
SW1: SW_Push; SW_PUSH_6mm_H4.3mm
U1: STM32F103C6Tx; LQFP-48_7x7mm_P0.5mm
U2: Ai-Thinker-Ra-02; Ai-Thinker-Ra-01-LoRa

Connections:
+3V3: C1.1, C2.1, C3.1, C5.1, C6.1, C7.2, J1.1, Q1.2 (S), R1.1, R2.2, R5.2, U1.1 (VBAT), U1.9 (VDDA), U1.24 (VDD), U1.36 (VDD), U1.48 (VDD); also elsewhere on the board
+5V0: J6.6, R9.2; also elsewhere on the board
/INFO_BUZZER: R6.1, U1.38 (PA15)
/INFO_LED: R3.1, U1.28 (PB15)
/LORA EN: R4.1, U1.22 (PB11)
/LORA_MISO: U1.16 (PA6), U2.13 (MISO)
/LORA_MOSI: U1.17 (PA7), U2.14 (MOSI)
/LORA_NSS: U1.14 (PA4), U2.15 (~NSS)
/LORA_SCK: U1.15 (PA5), U2.12 (SCK)
/PB0: U1.18 (PB0), U2.5 (DIO0)
/PB12: J6.3, U1.25 (PB12)
/RESET_PIN: C4.1, R1.2, SW1.2, U1.7 (NRST)
/SENSOR DATA: R7.1, R8.1, U1.10 (PA0)
/SWCLK: J1.3, U1.37 (PA14)
/SWDIO: J1.2, U1.34 (PA13)
GNDD: C1.2, C2.2, C3.2, C4.2, C5.2, C6.2, C7.1, C8.2, J1.4, J3.2, J5.2, J6.2, J6.4, R8.2, SW1.1, U1.8 (VSSA), U1.23 (VSS), U1.35 (VSS), U1.47 (VSS), U2.1 (GND), U2.2 (GND), U2.9 (GND), U2.16 (GND); also elsewhere on the board
unnamed: BZ1.1 (+), J4.1
unnamed: BZ1.2 (-), J4.2
unnamed: D1.1 (K), J2.2
unnamed: D1.2 (A), J2.1
unnamed: J3.1, R3.2
unnamed: J5.1, R6.2
unnamed: C8.1, J6.1, R9.1
unnamed: J6.5, R7.2
unnamed: Q1.3 (D), U2.3 (VDD)
unnamed: Q1.1 (G), R4.2, R5.1
unnamed: R2.1, U2.4 (~RESET)
SENSOR EN: U1.21 (PB10); also elsewhere on the board

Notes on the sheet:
SWD Interface
RESET Button
External LED Indicator
External BUZZER
EXTERNAL
Optical smole dust/smoke sensor Sharp

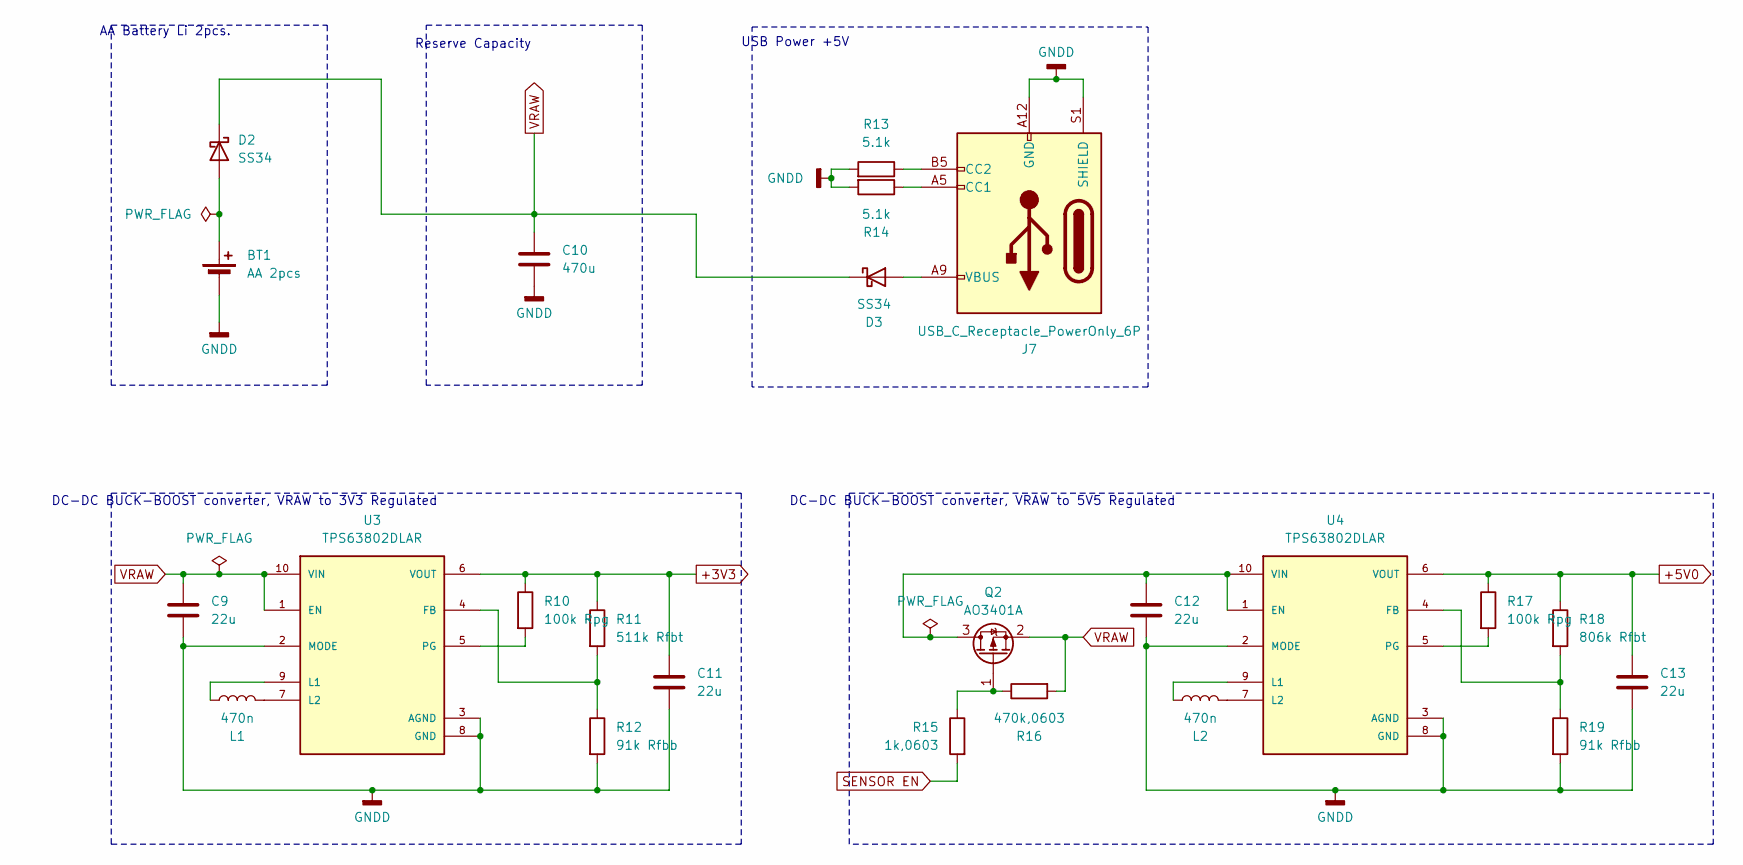
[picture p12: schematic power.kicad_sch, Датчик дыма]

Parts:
BT1: AA 2pcs; BatteryHolder_Keystone_2462_2xAA
C9, C11, C12, C13: 22u; C_0603_1608Metric_Pad1.08x0.95mm_HandSolder
C10: 470u; C_0805_2012Metric_Pad1.18x1.45mm_HandSolder
D2, D3: SS34; D_SMA
J7: USB_C_Receptacle_PowerOnly_6P; USB_C_Receptacle_GCT_USB4135-GF-A_6P_TopMnt_Horizontal
L1, L2: 470n; L_Coilcraft_XxL4020
Q2: AO3401A; SOT-23-3
R10, R17: 100k Rpg; R_0603_1608Metric_Pad0.98x0.95mm_HandSolder
R11: 511k Rfbt; R_0603_1608Metric_Pad0.98x0.95mm_HandSolder
R12, R19: 91k Rfbb; R_0603_1608Metric_Pad0.98x0.95mm_HandSolder
R13, R14: 5.1k; R_0603_1608Metric_Pad0.98x0.95mm_HandSolder
R15: 1k,0603; R_0603_1608Metric_Pad0.98x0.95mm_HandSolder
R16: 470k,0603; R_0603_1608Metric_Pad0.98x0.95mm_HandSolder
R18: 806k Rfbt; R_0603_1608Metric_Pad0.98x0.95mm_HandSolder
U3, U4: TPS63802DLAR; VREG_TPS63802DLAR; PARTREV B

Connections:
+3V3: C11.1, R10.1, R11.1, U3.6 (VOUT); also elsewhere on the board
+5V0: C13.1, R17.1, R18.1, U4.6 (VOUT); also elsewhere on the board
GNDD: BT1.2 (-), C9.2, C10.2, C11.2, C12.2, C13.2, J7.A12 (GND), J7.B12 (GND), J7.S1 (SHIELD), R12.2, R13.2, R14.2, R19.2, U3.2 (MODE), U3.3 (AGND), U3.8 (GND), U4.2 (MODE), U4.3 (AGND), U4.8 (GND); also elsewhere on the board
unnamed: BT1.1 (+), D2.2 (A)
unnamed: D3.2 (A), J7.A9 (VBUS), J7.B9 (VBUS)
unnamed: J7.A5 (CC1), R14.1
unnamed: J7.B5 (CC2), R13.1
unnamed: C12.1, Q2.3 (D), U4.1 (EN), U4.10 (VIN)
unnamed: Q2.1 (G), R15.1, R16.1
unnamed: R11.2, R12.1, U3.4 (FB)
unnamed: L1.2, U3.9 (L1)
unnamed: L1.1, U3.7 (L2)
unnamed: R10.2, U3.5 (PG)
unnamed: R18.2, R19.1, U4.4 (FB)
unnamed: L2.2, U4.9 (L1)
unnamed: L2.1, U4.7 (L2)
unnamed: R17.2, U4.5 (PG)
SENSOR EN: R15.2; also elsewhere on the board
VRAW: C9.1, C10.1, D2.1 (K), D3.1 (K), Q2.2 (S), R16.2, U3.1 (EN), U3.10 (VIN)

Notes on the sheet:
AA Battery Li 2pcs.
DC-DC BUCK-BOOST converter, VRAW to 3V3 Regulated
Reserve Capacity
DC-DC BUCK-BOOST converter, VRAW to 5V5 Regulated
USB Power +5V

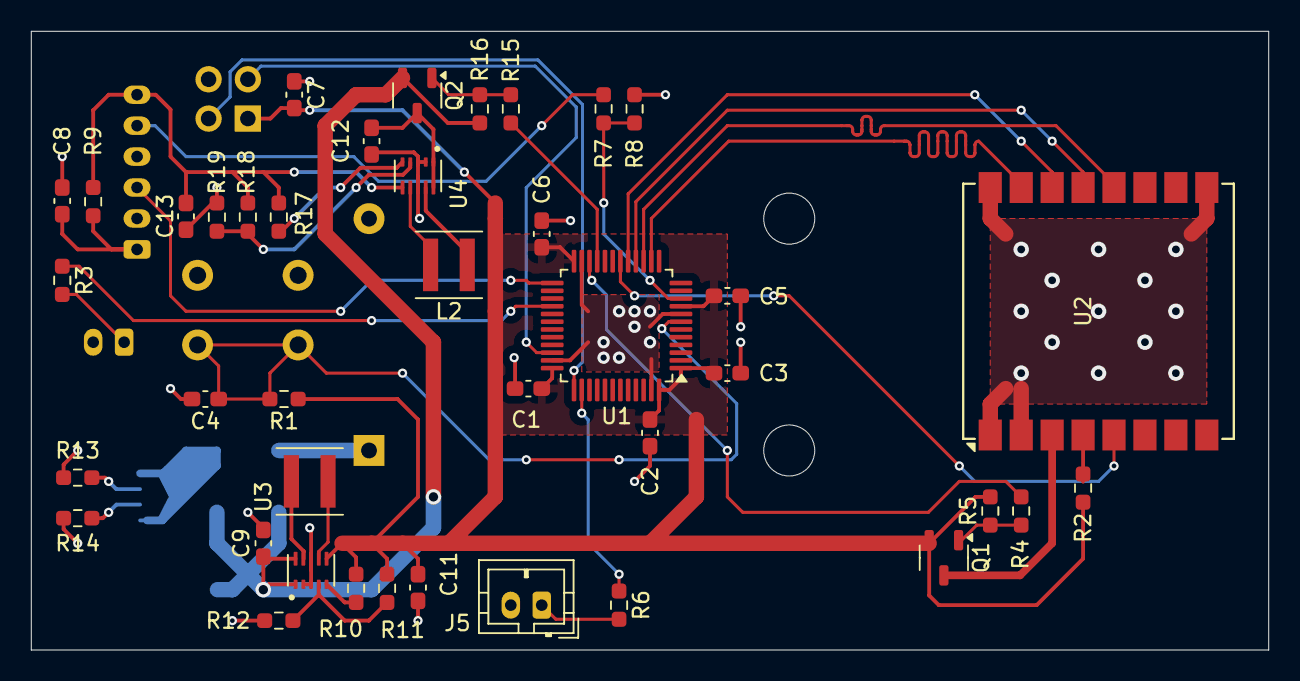
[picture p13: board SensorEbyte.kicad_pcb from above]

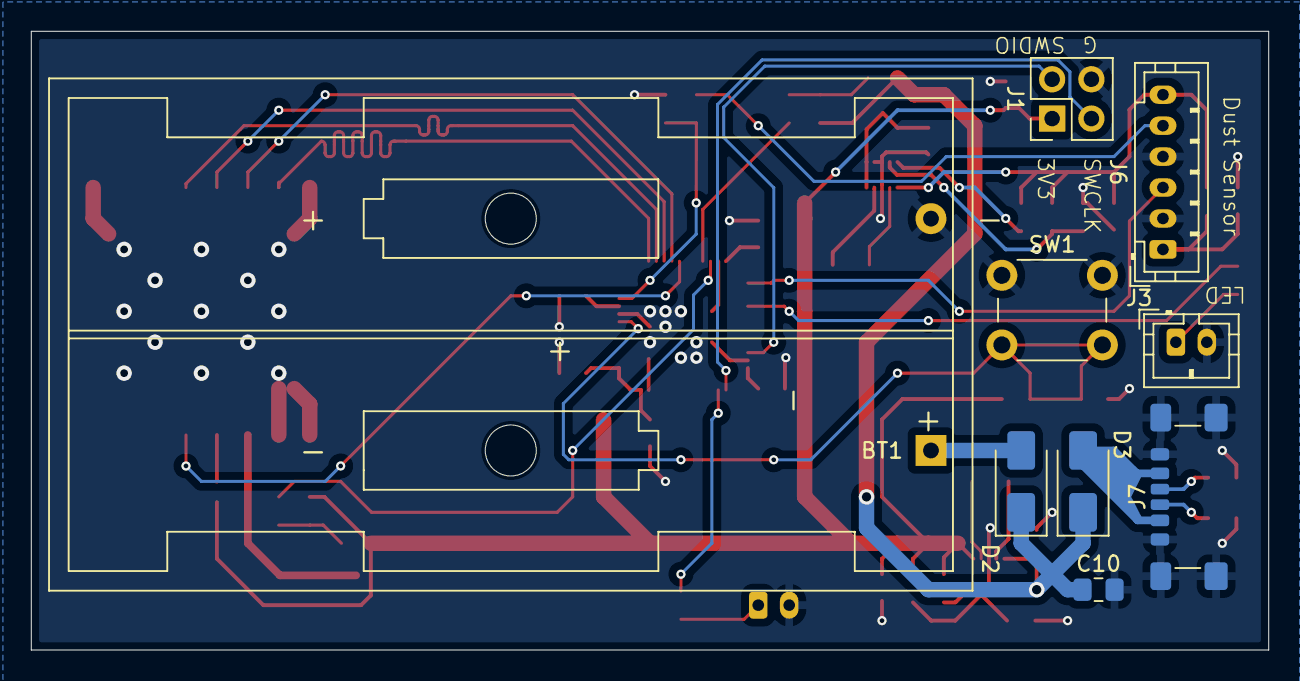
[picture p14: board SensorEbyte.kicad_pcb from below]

Board: 2 copper layers, 80.0 x 40.0 mm, 49 parts (9 on the bottom side), 39 nets.

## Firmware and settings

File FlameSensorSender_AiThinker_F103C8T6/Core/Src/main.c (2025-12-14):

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
/* Includes ------------------------------------------------------------------*/
#include "main.h"
#include "adc.h"
#include "rtc.h"
#include "spi.h"
#include "tim.h"
#include "usart.h"
#include "gpio.h"

/* USER CODE BEGIN Includes */
#include "adc.h"
#include "spi.h"
#include <stdio.h>
#include "DebugLog.h"
#include "Types.h"
#include "AlarmReset.h"
#include "SerialNumber.h"
#include "BatteryLevel.h"
#include "InfraSensor.h"
#include "BackupReg.h"
#include <stdbool.h>
#include "DataStorage.h"
#include "LoraSender.h"

/* USER CODE END Includes */


void SystemClock_Config(void);
/**
  * @brief  The application entry point.
  * @retval int
  */
int main(void)
{

  /* MCU Configuration--------------------------------------------------------*/

  /* Reset of all peripherals, Initializes the Flash interface and the Systick. */
  HAL_Init();

  /* Configure the system clock */
  SystemClock_Config();

  /* Initialize all configured peripherals */
  MX_GPIO_Init();
  MX_ADC1_Init();
  MX_ADC2_Init();
  MX_RTC_Init();
  MX_SPI1_Init();
  MX_TIM2_Init();
  MX_USART1_UART_Init();
  /* USER CODE BEGIN 2 */

	Settings_t settings;
	SerialNumber_t hw_serial;
	Battery_t Battery;
	SendPacket_t packet;

	bool ALERT_FLAG = false;

	debug_init(&huart1);

	debug("========================");
	debug("The device has woken up!");

	settings = retrieveSettingsFromFlash();

	debug("\tAlarm level: %d.%02d", (uint8_t) settings.alarm_level,
			(uint8_t) (settings.alarm_level * 100) % 100);
	debug("\tSleep time: %d sec", settings.sleep_time);
	debug("\tHeartbeat every: %d time\n\r", settings.times_to_heartbeat);

	MX_ADC1_Init();
	Battery = get_battery_level(&hadc1);
	HAL_ADC_DeInit(&hadc1);

	// Powering VCC to Smoke Sensor and polling for data
	MX_ADC2_Init();
	HAL_GPIO_WritePin(GPIOB, MOSFET_GATE_SENSOR_Pin, GPIO_PIN_SET);
	float sensor_data = get_infra_sensor_data(&hadc2, 1);
	if (sensor_data >= settings.alarm_level) {
		sensor_data = get_infra_sensor_data(&hadc2, 3);
		if (sensor_data >= settings.alarm_level)
			ALERT_FLAG = true;
	}
	HAL_GPIO_WritePin(GPIOB, MOSFET_GATE_SENSOR_Pin, GPIO_PIN_RESET);
	HAL_ADC_DeInit(&hadc2);

	init_backup_register();
	uint8_t backup_reg_current_value = read_backup_register();
	debug("Sleeps to heartbeat: %d of %d\n\r", backup_reg_current_value + 1,
			settings.times_to_heartbeat);

	if ((backup_reg_current_value + 1 >= settings.times_to_heartbeat)
			|| ALERT_FLAG) {

		hw_serial = get_serial_number();

		packet.ID = hw_serial.byte_2;
		packet.battery_level = Battery.charge_percent;
		packet.sensor_data = sensor_data;
		debug("Formed packet:");
		debug("\tID: %d", (uint8_t) packet.ID);
		debug("\tbattery_level: %d%%", (uint8_t) Battery.charge_percent);
		debug("\tsensor_data: %d.%02d\n\r", (uint8_t) sensor_data,
				(uint16_t) (sensor_data * 100) % 100);

		HAL_GPIO_WritePin(GPIOB, MOSFET_GATE_LORA_Pin, GPIO_PIN_SET);
		MX_SPI1_Init();
		send_packet(&hspi1, packet);
		HAL_GPIO_WritePin(GPIOB, MOSFET_GATE_LORA_Pin, GPIO_PIN_RESET);

		write_backup_register(0);
	} else {
		write_backup_register(++backup_reg_current_value);
	}

	if (ALERT_FLAG) {
		debug("\n\rBUZZ BUZZ BUZZ\n\r\n\r");

		HAL_GPIO_WritePin(GPIOB, MOSFET_GATE_SENSOR_Pin, GPIO_PIN_SET);
		for (int i = 0; i < 3; i++) {
			HAL_GPIO_WritePin(BUZZER_GPIO_Port, BUZZER_Pin, GPIO_PIN_SET);
			HAL_Delay(500);
			HAL_GPIO_WritePin(BUZZER_GPIO_Port, BUZZER_Pin, GPIO_PIN_RESET);
			HAL_Delay(500);
		}
		HAL_GPIO_WritePin(GPIOB, MOSFET_GATE_SENSOR_Pin, GPIO_PIN_RESET);

		settings.sleep_time = 5;
	}

	//  Toggling RED LED
	HAL_GPIO_WritePin(INFO_LED_GPIO_Port, INFO_LED_Pin, GPIO_PIN_SET);
	HAL_Delay(1);
	HAL_GPIO_WritePin(INFO_LED_GPIO_Port, INFO_LED_Pin, GPIO_PIN_RESET);

	// Sleeping
	set_alarm(&hrtc, settings.sleep_time);

	debug("Going STANDBY MODE\n\r\n\r");

	HAL_PWR_EnterSTANDBYMode();
  /* USER CODE END 2 */

  /* Infinite loop */
  /* USER CODE BEGIN WHILE */
	while (1) {
    /* USER CODE END WHILE */

    /* USER CODE BEGIN 3 */

	}
  /* USER CODE END 3 */
}

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
/* USER CODE BEGIN 4 */
void HAL_RTC_AlarmAEventCallback(RTC_HandleTypeDef *hrtc) {
	// Просто заглушка — достаточно, чтобы выйти из Standby
	debug("RTC Alarm Callback triggered!\n\r");
}
/* USER CODE END 4 */
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


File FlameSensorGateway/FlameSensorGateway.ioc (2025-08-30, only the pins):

Mcu.UserName=STM32H562RGTx
PA1.GPIO_Label=LORA_DIO1
PA1.Signal=GPXTI1
PA10.Signal=LPUART1_RX
PA13(JTMS/SWDIO).Signal=DEBUG_JTMS-SWDIO
PA14(JTCK/SWCLK).Signal=DEBUG_JTCK-SWCLK
PA2.GPIO_Label=LORA_BUSY
PA2.Signal=GPIO_Input
PA3.GPIO_Label=LORA_NRST
PA3.Signal=GPIO_Output
PA4.GPIO_Label=LORA_NSS
PA4.Signal=GPIO_Output
PA5.Signal=SPI1_SCK
PA6.Signal=SPI1_MISO
PA7.Signal=SPI1_MOSI
PA9.Signal=LPUART1_TX
PB14.Signal=USART1_TX
PB15.Signal=USART1_RX
PB2.GPIO_Label=SMALL_INFO_LED
PB2.Signal=GPIO_Output
PB6.Signal=I2C1_SCL
PB7.Signal=I2C1_SDA
PC14-OSC32_IN(OSC32_IN).Signal=RCC_OSC32_IN
PC15-OSC32_OUT(OSC32_OUT).Signal=RCC_OSC32_OUT
PH0-OSC_IN(PH0).Signal=RCC_OSC_IN
PH1-OSC_OUT(PH1).Signal=RCC_OSC_OUT

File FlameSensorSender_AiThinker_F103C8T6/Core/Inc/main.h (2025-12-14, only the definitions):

#define SMALL_INFO_LED_Pin GPIO_PIN_13
#define SMALL_INFO_LED_GPIO_Port GPIOC
#define INFO_LED_Pin GPIO_PIN_14
#define INFO_LED_GPIO_Port GPIOC
#define V0_Pin GPIO_PIN_0
#define V0_GPIO_Port GPIOA
#define VCC_BAT_Pin GPIO_PIN_1
#define VCC_BAT_GPIO_Port GPIOA
#define LORA_NSS_Pin GPIO_PIN_4
#define LORA_NSS_GPIO_Port GPIOA
#define LORA_DIO1_Pin GPIO_PIN_0
#define LORA_DIO1_GPIO_Port GPIOB
#define LORA_DIO1_EXTI_IRQn EXTI0_IRQn
#define LORA_NRST_Pin GPIO_PIN_1
#define LORA_NRST_GPIO_Port GPIOB
#define LORA_BUSY_Pin GPIO_PIN_2
#define LORA_BUSY_GPIO_Port GPIOB
#define MOSFET_GATE_SENSOR_Pin GPIO_PIN_10
#define MOSFET_GATE_SENSOR_GPIO_Port GPIOB
#define MOSFET_GATE_LORA_Pin GPIO_PIN_11
#define MOSFET_GATE_LORA_GPIO_Port GPIOB
#define V_LED_Pin GPIO_PIN_12
#define V_LED_GPIO_Port GPIOB
#define BUZZER_Pin GPIO_PIN_15
#define BUZZER_GPIO_Port GPIOA

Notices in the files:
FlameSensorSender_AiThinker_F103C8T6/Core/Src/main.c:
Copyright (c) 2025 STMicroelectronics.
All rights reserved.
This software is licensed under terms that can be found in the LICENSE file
